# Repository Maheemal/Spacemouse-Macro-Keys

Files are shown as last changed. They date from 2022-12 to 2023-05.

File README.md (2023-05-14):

# SpaceMouse-Macro-Pad

### Macro Pad for 3DConnexion SpaceMouse Wireless

## :blue_book: Introduction



Customizable macro pad for users of 3DConnexion SpaceMouse Wireless. Adds 12 easy-to-reach customizable buttons to the side of the SpaceMouse

## :battery: Making

If you are just looking to make one as is, download the latest release and follow the Build instructions on ```./Production Files```. Requires decent soldering skills. Alternatively, you can order the "mostly" assembled PCB from [PCBWay](https://www.pcbway.com/project/shareproject/SpaceMouse_Macro_Pad_0eddd3f1.html).

If you would like to purchase one, please contact via [hello@maheemal.com](mailto:hello@maheemal.com)

## :clipboard: Licence 

**Non-commercial use** - Free to use. Feel free to buy me a coffee ~> <a href="https://www.buymeacoffee.com/MaheemalKB" target="_blank">Buy Me A Coffee</a>

**Commercial use** - If you are a freelancer / professional / plan to use this in service of paid work / building one for someone other than yourself, please email me beforehand: [hello@maheemal.com](mailto:hello@maheemal.com)

## :white_check_mark: To-Do

Contributions are always welcome!

### PCB To-Do
- [ ] Remove vias underneath XIAO-RP2040
- [ ] Correct power out for SpaceMouse charging
- [ ] Set LEDs to drain to I/O pins (currently can only power Red LEDs)
### Enclosure To-Do
- [ ] Add SpaceMouse charging compatibility
### Code To-Do
- [ ] Make key bindings program specific
- [ ] Add additional keyboard layouts
### Wishlist
- [ ] Make device wireless

## :loudspeaker: Credit / Acknowledgements

- Original inspiration - [MiRage Modular Keyboard](https://github.com/zackfreedman/mirage)
- I/O Expander Library - [PCA9505 / PCA9506 Arduino Library](https://github.com/tofuman0/PCA9505_06)

## :link: Links
- [My Portfolio](https://www.maheemal.com/)
- [YouTube](https://www.youtube.com/@buxzed)

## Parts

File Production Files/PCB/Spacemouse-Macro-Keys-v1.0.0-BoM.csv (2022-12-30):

Designator | Quantity | Value | Footprint | LCSC Part #
C1, C2, | 2 | 0.1uF | 0603 | C14663
D1, D2, D3, D4, D5, D6, D7, D8, D9, D10, D11, D12, | 12 | LED | 0603 | C2286
R1, R2, R3, R4, R5, R6, R7, R8, R9, R10, R11, R12, | 12 | R100 | 0603 | C22775
R13, R16, R17, | 3 | 4.7k | 0603 | C23162

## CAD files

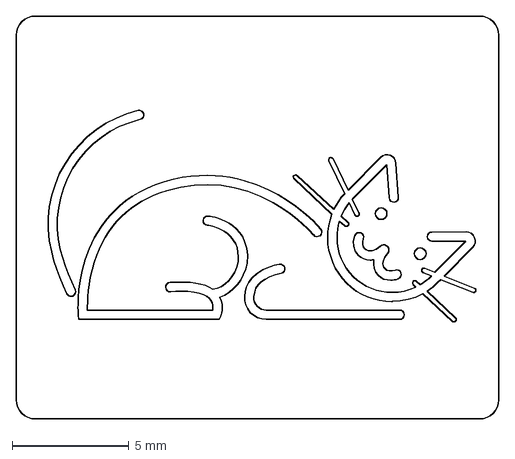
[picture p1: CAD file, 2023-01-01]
Production Files/Enclosure/Label Cat Logo.DXF
20.7 x 17.3 mm

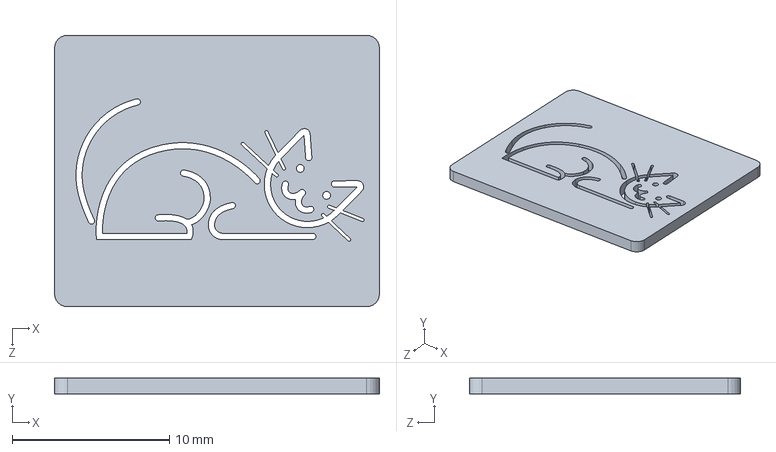
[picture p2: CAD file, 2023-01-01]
Source Files/CAD/Label Cat Logo.SLDPRT
20.7 x 1.00 x 17.3 mm

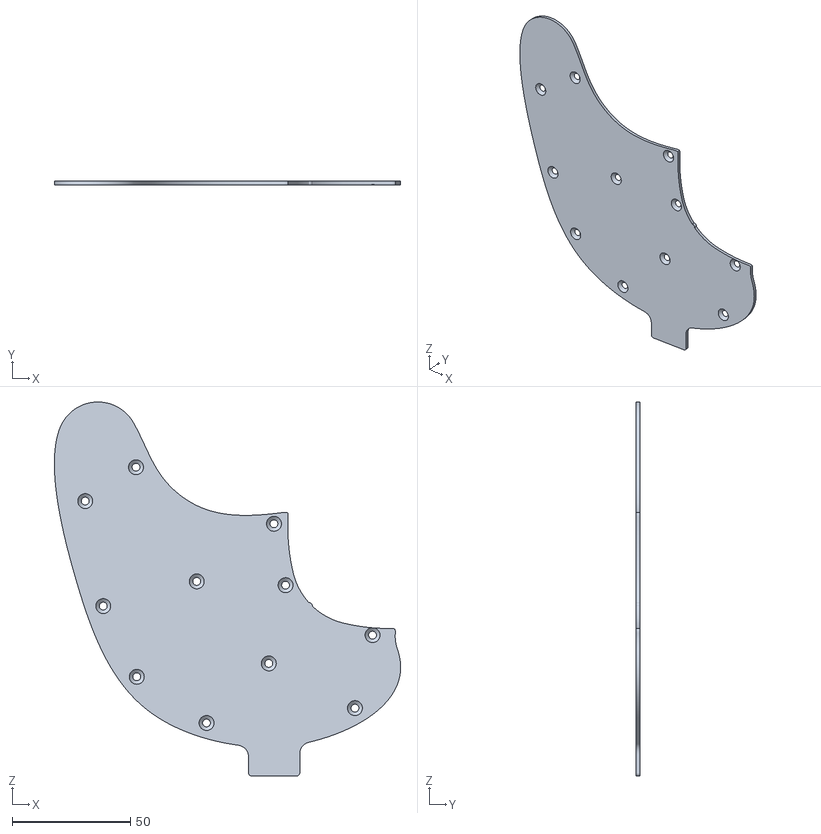
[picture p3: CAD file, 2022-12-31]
Production Files/Enclosure/SM_MacroPad Bottom.STL
146.2 x 1.50 x 157.9

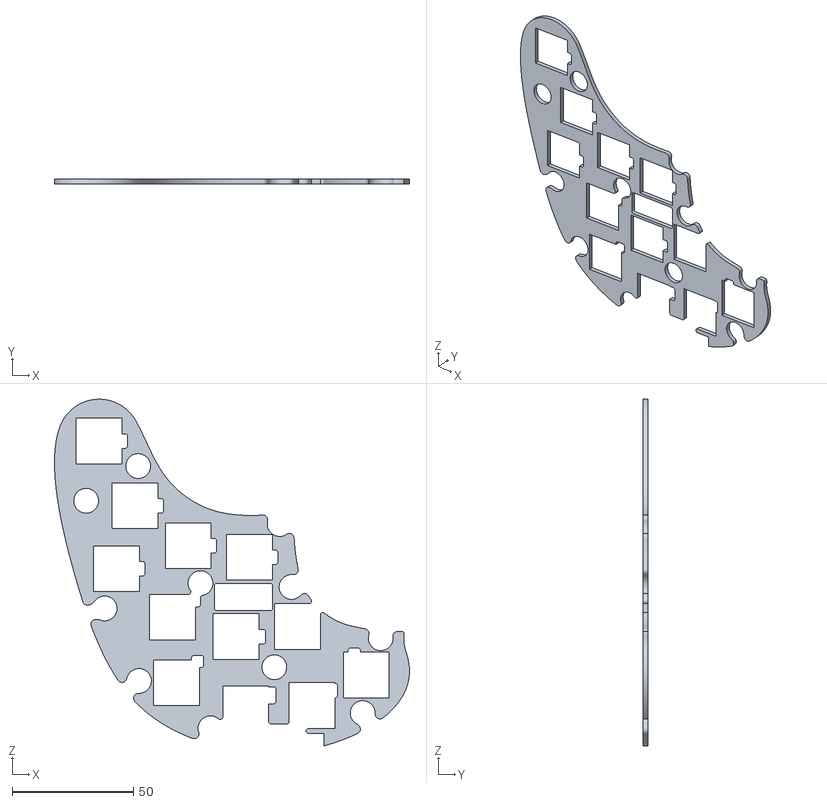
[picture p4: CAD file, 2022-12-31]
Production Files/Enclosure/SM_MacroPad Light Guide.STL
146.2 x 2.00 x 142.8

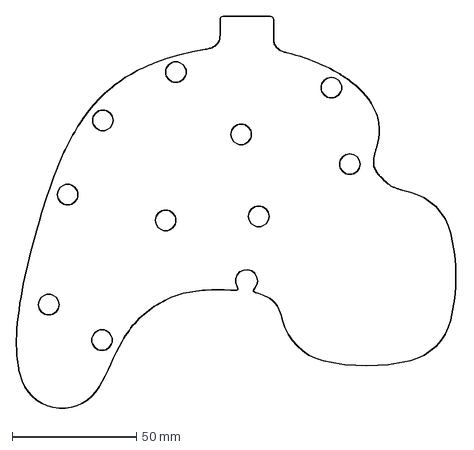
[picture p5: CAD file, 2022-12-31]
Production Files/Enclosure/SM_MacroPad Bottom Rubber Pad.DXF
177.8 x 158.4 mm

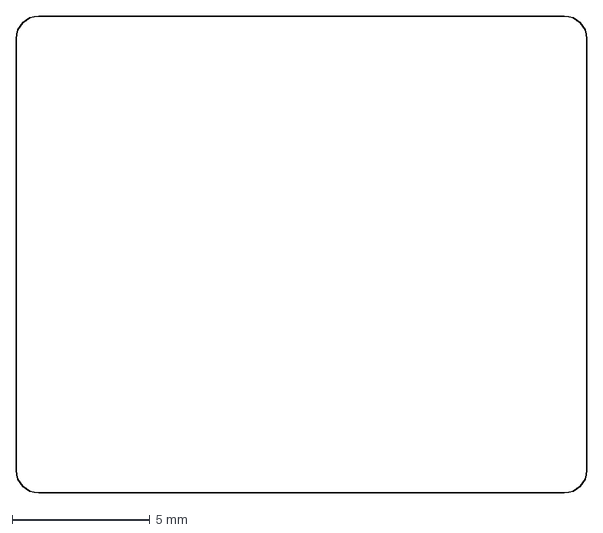
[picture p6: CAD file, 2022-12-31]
Production Files/Enclosure/Label Outline.DXF
20.7 x 17.3 mm

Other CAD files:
Production Files/Enclosure/SM_MacroPad Bottom.DXF
Production Files/Enclosure/SM_MacroPad Light Guide.DXF

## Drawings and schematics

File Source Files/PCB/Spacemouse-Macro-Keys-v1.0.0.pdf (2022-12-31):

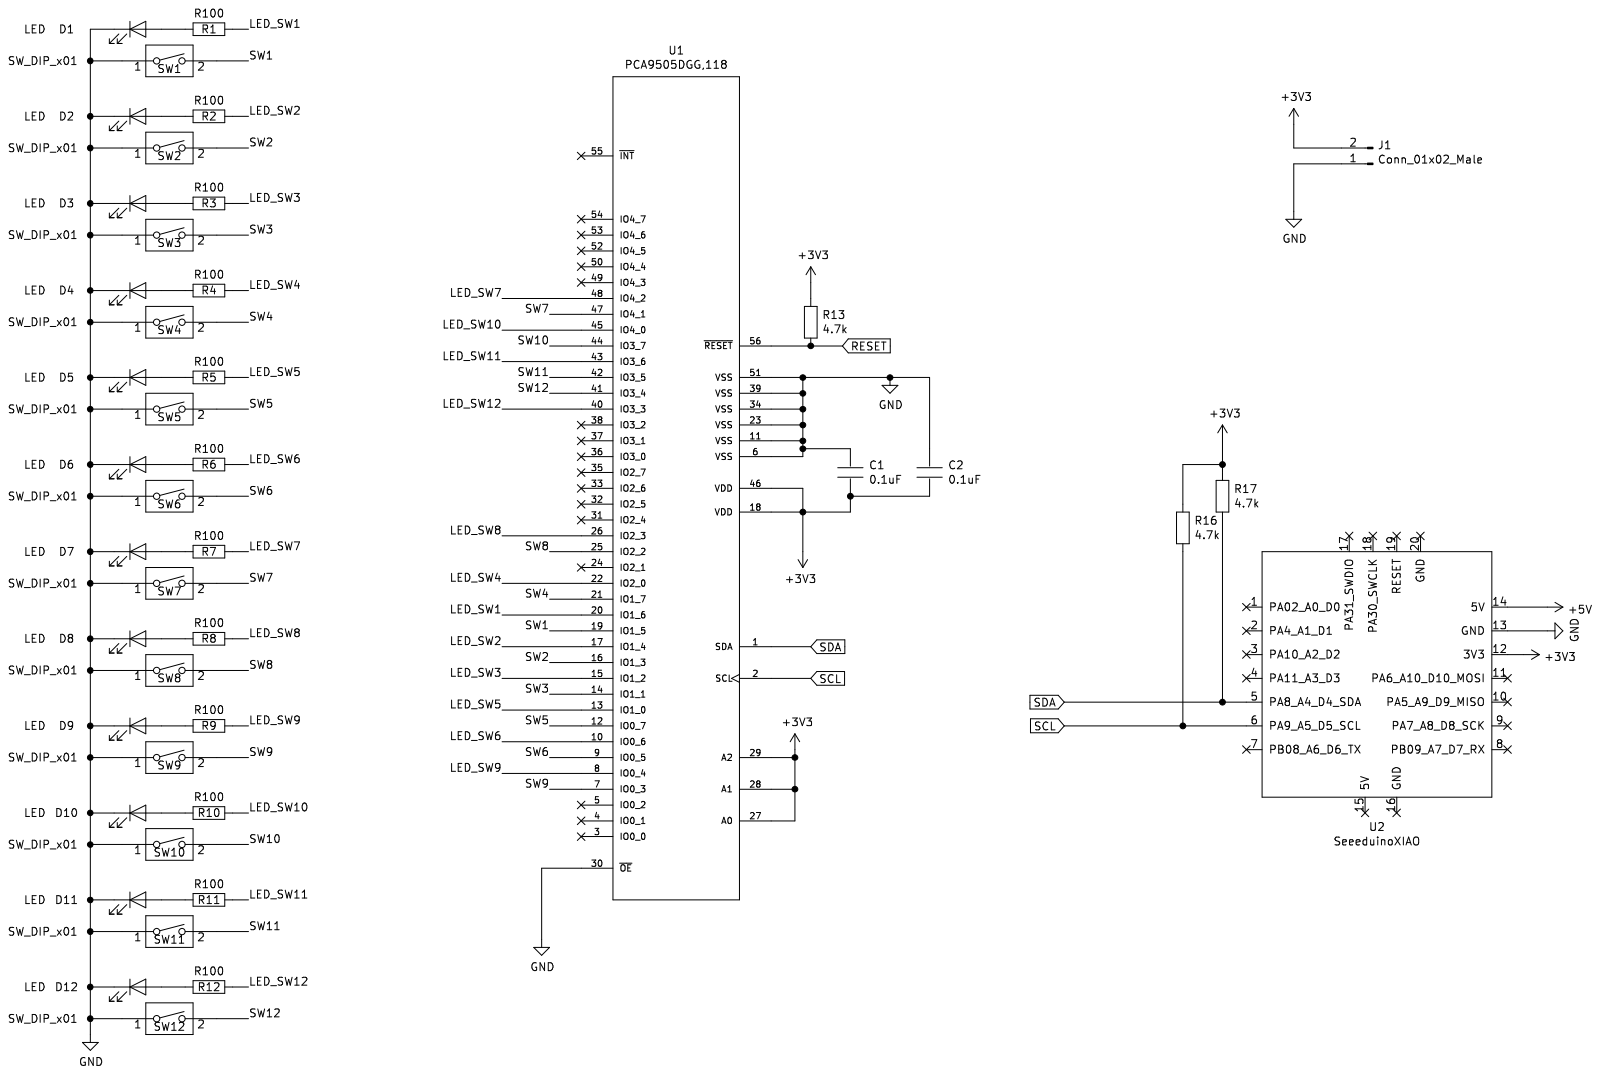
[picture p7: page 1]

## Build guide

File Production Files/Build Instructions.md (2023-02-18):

# Make Instructions

### Not a Step by step guide!

Spacemouse Advance Main

## BoM

| | Name | Quantity | Cost | Notes |
| ---- | --- | --- | --- | --- |
| 01 | SM_MacroPad Top Shell<br />```./Production Files/Enclosure``` | 1 | £15.50 / $18.70 | 3D Printed at home or [JLCPCB](https://jlcpcb.com/3d-printing), [HUBS](https://www.hubs.com/), [Weerg](https://www.weerg.com/) etc<br />I SLS printed mine with "Nylon PA12" |
| 02 | PCB ~> Spacemouse-Macro-Keys-v1.0.0<br />```./Production Files/PCB``` | 1 | £17.00 / $20.50 | PCB together with most SMD components. CPL and BoM files are provided for automated assembly. If hand assembling, components listed in ```Spacemouse-Macro-Keys-v1.0.0-BoM.csv``` need to also be sourced.<br />I used [JLCPCB](https://jlcpcb.com/) together with their assembly service. |
| 03 | [Seeed Studio XIAO RP2040](https://wiki.seeedstudio.com/XIAO-RP2040/) | 1 | £8.20 / $10.00  | Cover the bottom bonding pads with Kapton tape before soldering to the PCB. This is to prevent these pads from shorting to the vias on PCB. |
| 04 | [PCA9505](https://www.nxp.com/docs/en/data-sheet/PCA9505_9506.pdf) | 1 | £2.52 / $3.00 | In short supply. I purchased mine on [AliExpress](https://www.aliexpress.com) |
| 05 | Kailh LP Switch | 12 | £19.60 / $23.60 | I used ```57gf blue``` switches. feel free to use different speck keys<br />Datasheet can be found in ```./Source Files/Datasheets``` |
| 06 | Kailh LP Keycaps | 12 | £15.17 / $18.27 | I went with ```Black-chocolate```. Personal preference |
| 07 | M3 Brass Threaded Insert | 11 | | To be inserted into the 3D Printed "SM_MacroPad Top Shell" |
| 08 | M3 x 6mm Countersunk Screws | 11 | | |
| 09 | SM_MacroPad Bottom Rubber Pad<br />```./Production Files/Enclosure``` | 1 | | Grippy layer so the device doesn't slide around when using. I laser-cut mine from Self Adhesive Foam Sheets.<br />Alternatively, use suitable self-adhesive rubber feat |
| 10 | SM_MacroPad Bottom<br />```./Production Files/Enclosure``` | 1 | | Can be laser cut (2 mm) and countersunk manually, or 3D printed |
| 11 | SM_MacroPad Light Guide (Optional)<br />```./Production Files/Enclosure``` | 1 | | Laser-cut (2 mm) or 3D Print. Minimises light bleed |
| 12 | Label Outline (Optional)<br />```./Production Files/Enclosure``` | 1 | | Outline for product_info/logo sticker |

## Loading Firmware

1. Plug in the [Seeed Studio XIAO RP2040](https://wiki.seeedstudio.com/XIAO-RP2040/) to the computer in bootloader mode

   ```
   - Long press the "B" button.
   - Connect the Seeed Studio XIAO PR2040 to your computer.
   - The computer will appear as a disk drive.
   ```

2. Copy and paste "Spacemouse-Macro-Keys for seeed_xiao_rp2040_v1.0.0.uf2" file from ```./Production Files/Firmware``` to the bootloader

3. Wait for the device to restart

4. Each key is now a new Key on your HID. Go to the shortcut manager for your preferred program and assign keys as you wish.

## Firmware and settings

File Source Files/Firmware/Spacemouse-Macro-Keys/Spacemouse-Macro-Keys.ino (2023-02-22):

#include <PCA9505_9506.h> //Lib for handling I/O expander chip
#include <Keyboard.h> //HID keyboard lib

 
// Key assignments from switch 1 to 12
char Key_Assignment_Array[] = {KEY_F13, KEY_F14, KEY_F15, KEY_F16, KEY_F17, KEY_F18, KEY_F19, KEY_F20, KEY_F21, KEY_F22, KEY_F23, KEY_F24};

// LEDs under each switch 1 to 12
int LED_Array[] = {14, 12, 10, 16, 8, 6, 34, 19, 4, 32, 30, 27};

// GPIO pin for each switch on the I/O expander from 1 to 12
int Switch_Array[] = {13, 11, 9, 15, 7, 5, 33, 18, 3, 31, 29, 28};

bool is_pressed[12];

PCA9505_06 GPIO;

void setup() {


  GPIO.begin(0x27);   //  0x20 A0=1 A1=1 A2=1

  for (int i = 0; i < 12; i++){
    GPIO.pinMode(LED_Array[i], OUTPUT);   // configure LED_i as output
    GPIO.pinMode(Switch_Array[i], INPUT); // configure SWITCH_i as output
    is_pressed[i] = false;
  }
  
  Keyboard.begin();
}

void loop() {


  for (int i = 0; i < 12; i++){                     //scans through switches 1 to 12
    if (GPIO.digitalRead(Switch_Array[i]) == LOW){  // If SWITCH_i is pressed
      if (!is_pressed[i]) {
       GPIO.digitalWrite(LED_Array[i], HIGH);        // switch on LED_i
       Keyboard.press(Key_Assignment_Array[i]);      // Press KEY_i
       is_pressed[i] = true;
      }
    }

    else {
     if (is_pressed[i]) {
      GPIO.digitalWrite(LED_Array[i], LOW);         // switch off LED_i
      Keyboard.release(Key_Assignment_Array[i]);    // release KEY_i
      is_pressed[i] = false;
     }
    } 
  }
}

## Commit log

2022-12-31 PCB source files added
    [Spacemouse-Macro-Keys.kicad_sch]
2022-12-31 Production files added
    [Label Outline.DXF, SM_MacroPad Bottom Rubber Pad.DXF, SM_MacroPad Bottom.DXF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]
2023-01-01 Special key assignment changed to AHK
    The macro pad is now purely F keys. The assignment of special keys is now done through AHK. avoids having to access the bootloader to change keybindings
    [Spacemouse-Macro-Keys.ino]
2023-01-01 Engrave files added
    [Label Cat Logo.DXF, Label Cat Logo.SLDPRT]
2023-05-14 Update README.md
    The PCBWay project link added
